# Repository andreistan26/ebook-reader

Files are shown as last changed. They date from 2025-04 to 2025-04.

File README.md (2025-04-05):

# OpenBook - Andrei Stan 331CC

Untitled-2025-03-29-1929(1)

## Descriere Functionalitate Hardware
- Tableta este controlata prin cele 3 butoane
- ESP-ul comunica cu memoria flash si SD card-ul
- Trimite date la display pentru afisarea continutului din flash/sd card
- De la USB se folosesc linia de date si cea de putere pentru alimentare
- Linia de alimentare incarca bateria tabletei
- Se folosesc protocoalele i2c si spi pentru comunicatie
- UART se poate folosi prin testpad-uri pentru debugging
## ESP32 Pini
|Pin|Semnal|Descriere|
|---|---|---|
|EN|RESET|exact ce spune semanalul
|IO0|INT_RTC| conectat la modulul RTC care poate emite intreruperi la anumite alarme/timere
|IO1|32KHz| transmite un semanl de 32Khz care este folosit pentru ceasul tabletei
|IO2|MISO| pentru primirea datelor de la periferic (ex. SD card reader, Flash memorie)
|IO3|EPD_BUSY| pentru a trimite date numai atunci cand display-ul este gata de randat, epaper este incet, deci avem nevoie de acest semnal
|IO4|SS_SD| folosit pentru detectia sd cardului, daca este prezent
|IO5|EPD_DC| comunicatie seriala cu e-paper display-ul
|IO6|SCK| ceas pentru comunicatia SPI cu celelalte componente SPI
|IO7|MOSI| pentru transmisia informatiilor pentru card SD, memorie flash si display
|IO8|GPIO8| neutilizat
|IO9|IO/BOOT| a fost apasat butonul de pornire
|IO10|EPD_CS| Chip select pentru comunicatia seriala
|IO11|FLASH_CS| Chip select pentru memoria flash
|IO12|USB_D-| transfer de date USB diferential -
|IO13|USB_D+| transfer de date USB diferential +
|IO15|IO/Change| butonul de schimbat pagina este apasat
|TXD0| TX| Tx pe UART, este folosit numai la testpad-uri pentru debugging
|RXD0| RX| Rx pe UART, este folosit numai la testpad-uri  pentru debugging
|IO18| RTC_RST| resetare a ceasului de 32Khz
|IO19| I2C_PW| alimentare si chip-select pentru senzor
|IO20| EPD_3v3_c| controleaza transzistorul prin care este alimentat display-ul (nu putem alimenta direct din el sau cel putin e bad practice)
|IO21| SDA| linie de date pentru comunicarea i2c 
|IO22| SCL| semnalul de ceas pentru comunicatrea i2c
|IO23| EPD_RST| resetare a display-ului

## Design Log \ Decizii

* Mufa USB a fost modificata pentru a evita erorile DRC
* Traseele de putere au fost facute prima data, dupa care am folosit autorouter-ul pentru a completa
* Am mutat toate gaurile de pe carcasa si dimensiunile acesteia pentru a intra PCB ul

## BOM
|Qty|Device|Parts|DATASHEET|DESCRIPTION|MOUSER_PRICE-STOCK|
|---|---|-----|---|---|---|
|1|ADAFRUIT_LEDCHIP-LED0603|CHG_LED|https://www.vishay.com/doc?82437||https://ro.mouser.com/ProductDetail/Vishay-Semiconductors/VLMY1301-GS08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|
|1|ESP32_WROVER_EAGLE-LTSPICE_RR0402|R15|https://www.vishay.com/doc?20035||https://ro.mouser.com/ProductDetail/Vishay-Dale/CRCW040240K2FKED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|
|1|ESP32_WROVER_EAGLE-LTSPICE_RR0402|R21|https://www.vishay.com/doc?20035|||
|7|EAGLE-LTSPICE_CC0402|"C3, C4, C5, C9, C18, C19, C_DELAY"|https://ro.mouser.com/datasheet/2/447/KEM_C1006_X5R_SMD-3316465.pdf||https://ro.mouser.com/ProductDetail/KEMET/C0402C475K8PACTU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|
|2|ESP32_WROVER_EAGLE-LTSPICE_CC0402|"C24, C25"|https://ro.mouser.com/datasheet/2/447/KEM_C1006_X5R_SMD-3316465.pdf||https://ro.mouser.com/ProductDetail/KEMET/C0402C475K8PACTU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|
|1|RCL_CPOL-EUCT3528|C28|https://ro.mouser.com/datasheet/2/447/KEM_T2073_T59X-3316825.pdf||https://ro.mouser.com/ProductDetail/KEMET/T598B335M035ATE150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|
|1|ESP32_WROVER_EAGLE-LTSPICE_RR0402|R14|https://www.vishay.com/doc?20035||https://ro.mouser.com/ProductDetail/Vishay-Dale/CRCW040240K2FKED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|
|12|ESP32_WROVER_EAGLE-LTSPICE_RR0402|"R1, R1_PINH1, R2, R2_PINH1, R3, R5, R6, R7, R8, R10, R11, R17"|https://www.vishay.com/doc?20035|||
|3|ESP32_WROVER_EAGLE-LTSPICE_RR0402|"R_BOOT, R_CHANGE, R_RESET"|https://www.vishay.com/doc?20035|||
|1|ESP32_WROVER_EAGLE-LTSPICE_CC0402|C21|https://ro.mouser.com/datasheet/2/447/KEM_C1006_X5R_SMD-3316465.pdf||https://ro.mouser.com/ProductDetail/KEMET/C0402C475K8PACTU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|
|1|112A-TAAR-R03_ATTEND|J1|https://www.attend.com.tw/data/download/file/112A-TAAR-R03_Spec.pdf|"Micro SD Card Socket, Push-Push Type, Top Mount, SMT, H=1.83mm, 10u"|https://www.digikey.com/en/products/detail/attend-technology/112A-TAAR-R03/17633923|
|1|ESP32_WROVER_EAGLE-LTSPICE_RR0402|R_CAPACITOR|https://www.vishay.com/doc?20035|||
|1|EAGLE-LTSPICE_CC0402|C2|https://ro.mouser.com/datasheet/2/447/KEM_C1006_X5R_SMD-3316465.pdf||https://ro.mouser.com/ProductDetail/KEMET/C0402C475K8PACTU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|
|10|EAGLE-LTSPICE_CC0402|"C7, C8, C10, C11, C12, C13, C14, C15, C16, C17"|https://ro.mouser.com/datasheet/2/447/KEM_C1006_X5R_SMD-3316465.pdf||https://ro.mouser.com/ProductDetail/KEMET/C0402C475K8PACTU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|
|1|ESP32_WROVER_EAGLE-LTSPICE_RR0402|R12|https://www.vishay.com/doc?20035|||
|1|ESP32_WROVER_EAGLE-LTSPICE_RR0402|R1_BAT|https://www.vishay.com/doc?20035|||
|1|ESP32_WROVER_SPARKFUN-DISCRETESEMI_MOSFET_PCH-DMG2305UX-7|Q1|https://www.diodes.com/assets/Datasheets/DMG2305UX.pdf||https://www.digikey.ro/en/products/detail/diodes-incorporated/DMG2305UX-7/4340667|
|1|ESP32_WROVER_SPARKFUN-DISCRETESEMI_MOSFET_PCH-DMG2305UX-7|Q3|https://www.diodes.com/assets/Datasheets/DMG2305UX.pdf||https://www.digikey.ro/en/products/detail/diodes-incorporated/DMG2305UX-7/4340667|
|1|ESP32_WROVER_EAGLE-LTSPICE_RR0402|R16|https://www.vishay.com/doc?20035|||
|2|EAGLE-LTSPICE_CC0402|"C22, C23"|https://ro.mouser.com/datasheet/2/447/KEM_C1006_X5R_SMD-3316465.pdf||https://ro.mouser.com/ProductDetail/KEMET/C0402C475K8PACTU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|
|2|ESP32_WROVER_EAGLE-LTSPICE_CC0402|"C26, C27"|https://ro.mouser.com/datasheet/2/447/KEM_C1006_X5R_SMD-3316465.pdf||https://ro.mouser.com/ProductDetail/KEMET/C0402C475K8PACTU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|
|1|ESP32_WROVER_EAGLE-LTSPICE_CC0402|C20|https://ro.mouser.com/datasheet/2/447/KEM_C1006_X5R_SMD-3316465.pdf||https://ro.mouser.com/ProductDetail/KEMET/C0402C475K8PACTU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|
|2|ESP32_WROVER_EAGLE-LTSPICE_RR0402|"R19, R20"|https://www.vishay.com/doc?20035|||
|1|744043680IND_4828-WE-TPC_WRE|L3|https://www.we-online.com/components/products/datasheet/744043680.pdf||https://ro.mouser.com/ProductDetail/Wurth-Elektronik/744043680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|
|1|BD5229G-TR|IC1|https://fscdn.rohm.com/en/products/databook/datasheet/ic/power/voltage_detector/bd52xxg-e.pdf|"Voltage Detector with Adjustable Delay Time: CMOS processes are utilized to develop high precision  low current consumption CMOS reset ICs that allow arbitrary setting of the delay time. The extensive lineup includes both Nch Open Drain and CMOS output types in a wide range of detection voltages (from 2.3V to 6.0V, in 0.1V steps) enabling selection of the ideal solution based on customer requirements. In addition the entire series is of course both lead-free and RoHS-compliant."|https://www.mouser.co.uk/ProductDetail/ROHM-Semiconductor/BD5229G-TR?qs=4kLU8WoGk0vvnhrrYwdszw%3D%3D|
|1|ESP32_WROVER_BME680_BME680|SENSOR2|https://ro.mouser.com/datasheet/2/783/BST_BME680_DS001-1509608.pdf| Integrated Environmental Unit |https://ro.mouser.com/ProductDetail/Bosch-Sensortec/BME680?qs=v271MhAjFHjo0yA%2FC4OnDQ%3D%3D|
|3|BUTTON_CUSYOMV1|"BOOT_BUTTON, CHANGE_BUTTON, RESET_BUTTON"|https://4donline.ihs.com/images/VipMasterIC/IC/PANA/PANAS45028/PANAS45028-1.pdf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||https://ro.mouser.com/ProductDetail/Panasonic/EVQ-9P701P?qs=NPkb10g2yLBKCwpELvsGNg%3D%3D|
|1|CPH3225A|C6|https://mm.digikey.com/Volume0/opasdata/d220001/medias/docus/6537/rev05-CPHCPM.pdf| 11 mF (EDLC) Supercapacitor 3.3 V 1210 (3225 Metric) - - ||
|1|DS3231SN#|U4|https://ro.mouser.com/datasheet/2/609/DS3231-3421123.pdf| Extremely Accurate I C-Integrated RTC/TCXO/Crystal ||
|1|ESP32-C6-WROOM-1-N8|U1|https://www.espressif.com/sites/default/files/documentation/esp32-c6-wroom-1_wroom-1u_datasheet_en.pdf|" Multiprotocol Modules ESP32-C6 module, Wi-Fi 6 in 2.4 GHz band, Bluetooth 5, Zigbee 3.0 and Thread. ESP34-WROOM Compatible - ENGINEERING SAMPLE "||
|1|ESP32C6_VARISTORCN1812|R18|https://mm.digikey.com/Volume0/opasdata/d220001/medias/docus/2123/CTVS_Standard_Rev2015.pdf||https://www.digikey.be/en/products/detail/epcos-tdk-electronics/CN1812K11G/635074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|
|2|ESP32_WROVER_AVX---SD0805S020S1R0_AVX_SD0805S020S1R0_0_0AVX_SD0805S020S1R0_0_0|"D1, D13"|http://datasheets.avx.com/schottky.pdf|||
|1|ESP32_WROVER_SPARKFUN-IC-POWER_MCP73831|MCP73831|https://ro.mouser.com/datasheet/2/268/MCP73831_Family_Data_Sheet_DS20001984H-3441711.pdf||https://www.mouser.dk/ProductDetail/Microchip-Technology/MCP73831T-3ACI-OT?qs=yUQqVecv4quInAWkk8YFWg%3D%3D|
|1|FH34SRJ-24S-0.5SH_99_|J3|https://ro.mouser.com/datasheet/2/185/FH34SRJ_24S_0_5SH_99__CL0580_1255_6_99_2DDrawing_0-1615044.pdf|"24 Position FFC, FPC Connector Contacts, Top and Bottom 0.020"" (0.50mm) Surface Mount, Right Angle"|https://www.mouser.co.uk/ProductDetail/Hirose-Connector/FH34SRJ-24S-0.5SH99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|
|1|MAX17048G+T10|U2|https://ro.mouser.com/datasheet/2/609/MAX17048_MAX17049-3469099.pdf| 3 A 1-Cell/2-Cell Fuel Gauge with ModelGauge ||
|3|MBR0530|"D3, D5, D7"|https://www.onsemi.cn/pdf/datasheet/mbr0530-d.pdf| Diode Schottky 30 V 500mA Surface Mount SOD-123 ||
|6|PGB1010603MR|"D2, D4, D6, D8, D10, D11"|https://www.littelfuse.com/assetdocs/pulseguard-esd-suppressors-pgb1-datasheet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| 150V (Typ) Clamp - Ipp Tvs Diode Surface Mount 0603 (1608 Metric) ||
|1|QWIIC_CONNECTORJS-1MM|J2|https://ro.mouser.com/datasheet/2/813/Qwiic_Connector_Datasheet-1223982.pdf||https://ro.mouser.com/ProductDetail/SparkFun/PRT-14417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|
|1|SAMACSYS_PARTS_USB4110-GF-A|J4|https://ro.mouser.com/datasheet/2/837/GCT_USB4110_Product_Drawing___20k_cycles-3455479.pdf|CONN USB 2.0 TYPE-C R/A SMT|https://www.mouser.co.uk/ProductDetail/GCT/USB4110-GF-A?qs=KUoIvG%2F9IlYiZvIXQjyJeA%3D%3D|
|1|SI1308EDL-T1-GE3|Q2|https://www.vishay.com/docs/63399/si1308edl.pdf|" Si1308EDL-T1-GE3 N-channel MOSFET Transistor, 1.5 A, 30 V, 3-Pin SC-70 Siliconix / Vishay SI1308EDL-T1-GE3 "||
|1|USBLC6-2SC6Y|D9|https://ro.mouser.com/datasheet/2/389/usblc6_2sc6y-1852505.pdf| 17V Clamp 5A (8/20 s) Ipp Tvs Diode Surface Mount SOT-23-6 |https://ro.mouser.com/ProductDetail/STMicroelectronics/USBLC6-2SC6Y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|
|1|W25Q512JVEIQ|U3|https://www.winbond.com/resource-files/W25Q512JV%20SPI%20RevB%2006252019%20KMS.pdf| FLASH - NOR Memory IC 512Mb (64M x 8) SPI - Quad I/O 133 MHz 8-WSON (8x6) ||
|1|XC6220A331MR-G|IC2|https://ro.mouser.com/datasheet/2/760/xc6220-3371556.pdf|LDO Voltage Regulators|https://www.mouser.co.uk/ProductDetail/Torex-Semiconductor/XC6220A331MR-G?qs=AsjdqWjXhJ8ZSWznL1J0gg%3D%3D|

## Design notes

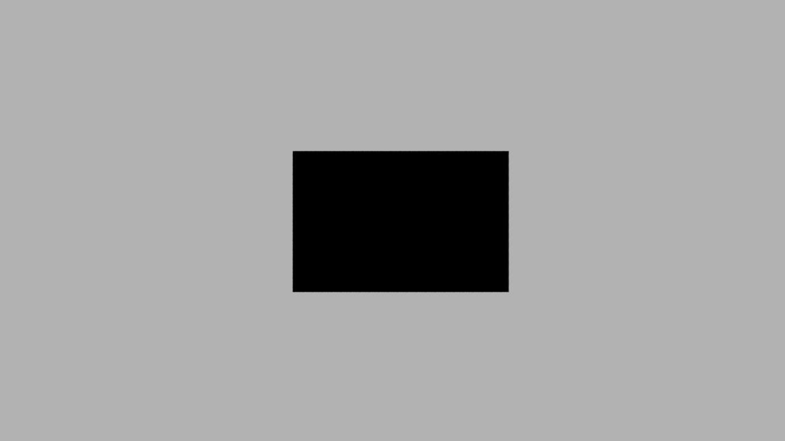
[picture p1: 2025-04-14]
Images/screen.png

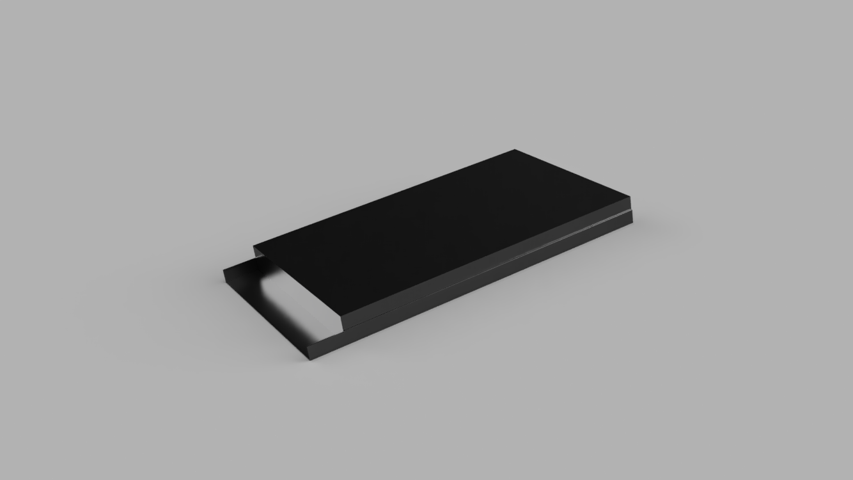
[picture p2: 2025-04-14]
Images/battery.png

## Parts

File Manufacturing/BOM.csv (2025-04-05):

Qty | Value | Device | Package | Parts | Description | ARROW_PART_NUMBER | ARROW_PRICE-STOCK | AVAILABILITY | CENTROID_NOT_SPECIFIED | CHECK_PRICES | COPYRIGHT | DATASHEET | DESCRIPTION | DIGIKEY_DESCRIPTION | DIGIKEY_PART_NUMBER | HEIGHT | LEAD_FREE | MANUFACTURER_NAME | MANUFACTURER_PART_NUMBER | MF | MFR_NAME | MOUSER_PART_NUMBER | MOUSER_PRICE-STOCK | MOUSER_TESTING_PART_NUMBER | MOUSER_TESTING_PRICE-STOCK | MP | MPN | PACKAGE | POPULARITY | PREFIX | PRICE | PROD_ID | PURCHASE-URL | ROHS | SNAPEDA_LINK | SPICEMODEL | SPICEPREFIX | TEMPERATURE_RANGE_HIGH | TEMPERATURE_RANGE_LOW | TP_SIGNAL_NAME | VALUE
1 |  | ADAFRUIT_LEDCHIP-LED0603 | ADAFRUIT_CHIP-LED0603 | CHG_LED | LED |  |  |  |  |  |  | https://www.vishay.com/doc?82437 |  |  |  |  |  |  |  |  |  |  | https://ro.mouser.com/ProductDetail/Vishay-Semiconductors/VLMY1301-GS08
1 |  | SJ | SJ | SJ1 | SMD solder JUMPER |  |  |  |  |  |  |  |  |  |  |  |  |  |  |  |  |  |  |  |  |  |  |  | 3
1 | 0.47 | ESP32_WROVER_EAGLE-LTSPICE_RR0402 | ESP32_WROVER_EAGLE-LTSPICE_R0402 | R15 | RESISTOR, European symbol |  |  |  |  |  |  | https://www.vishay.com/doc?20035 |  |  |  |  |  |  |  |  |  |  | https://ro.mouser.com/ProductDetail/Vishay-Dale/CRCW040240K2FKED?qs=rzhQWu8UUS3g49JmcwYN7w%3D%3D&gad_source=1 |  |  |  |  |  |  |  |  |  |  |  |  | NONE | R
1 | 100K | ESP32_WROVER_EAGLE-LTSPICE_RR0402 | ESP32_WROVER_EAGLE-LTSPICE_R0402 | R21 | RESISTOR, European symbol |  |  |  |  |  |  | https://www.vishay.com/doc?20035 |  |  |  |  |  |  |  |  |  | https://eu.mouser.com/ProductDetail/Vishay-Dale/CRCW040240K2FKED?qs=rzhQWu8UUS3g49JmcwYN7w%3D%3D&gad_source=1 |  |  |  |  |  |  |  |  |  |  |  |  |  | NONE | R
7 | 100nF | EAGLE-LTSPICE_CC0402 | EAGLE-LTSPICE_C0402 | C3, C4, C5, C9, C18, C19, C_DELAY | CAPACITOR, European symbol |  |  |  |  |  |  | https://ro.mouser.com/datasheet/2/447/KEM_C1006_X5R_SMD-3316465.pdf |  |  |  |  |  |  |  |  |  |  | https://ro.mouser.com/ProductDetail/KEMET/C0402C475K8PACTU |  |  |  |  |  |  |  |  |  |  |  |  | NONE | C
2 | 100nF | ESP32_WROVER_EAGLE-LTSPICE_CC0402 | ESP32_WROVER_EAGLE-LTSPICE_C0402 | C24, C25 | CAPACITOR, European symbol |  |  |  |  |  |  | https://ro.mouser.com/datasheet/2/447/KEM_C1006_X5R_SMD-3316465.pdf |  |  |  |  |  |  |  |  |  |  | https://ro.mouser.com/ProductDetail/KEMET/C0402C475K8PACTU |  |  |  |  |  |  |  |  |  |  |  |  | NONE | C
1 | 100uF | RCL_CPOL-EUCT3528 | RCL_CT3528 | C28 | POLARIZED CAPACITOR, European symbol |  |  |  |  |  |  | https://ro.mouser.com/datasheet/2/447/KEM_T2073_T59X-3316825.pdf |  |  |  |  |  |  |  |  |  |  | https://ro.mouser.com/ProductDetail/KEMET/T598B335M035ATE150 |  |  |  |  |  | 0 |  |  |  |  |  |  |  | C
1 | 10K | ESP32_WROVER_EAGLE-LTSPICE_RR0402 | ESP32_WROVER_EAGLE-LTSPICE_R0402 | R14 | RESISTOR, European symbol |  |  |  |  |  |  | https://www.vishay.com/doc?20035 |  |  |  |  |  |  |  |  |  |  | https://ro.mouser.com/ProductDetail/Vishay-Dale/CRCW040240K2FKED?qs=rzhQWu8UUS3g49JmcwYN7w%3D%3D&gad_source=1 |  |  |  |  |  |  |  |  |  |  |  |  | NONE | R
12 | 10K | ESP32_WROVER_EAGLE-LTSPICE_RR0402 | ESP32_WROVER_EAGLE-LTSPICE_R0402 | R1, R1_PINH1, R2, R2_PINH1, R3, R5, R6, R7, R8, R10, R11, R17 | RESISTOR, European symbol |  |  |  |  |  |  | https://www.vishay.com/doc?20035 |  |  |  |  |  |  |  |  |  | https://eu.mouser.com/ProductDetail/Vishay-Dale/CRCW040240K2FKED?qs=rzhQWu8UUS3g49JmcwYN7w%3D%3D&gad_source=1 |  |  |  |  |  |  |  |  |  |  |  |  |  | NONE | R
3 | 10k | ESP32_WROVER_EAGLE-LTSPICE_RR0402 | ESP32_WROVER_EAGLE-LTSPICE_R0402 | R_BOOT, R_CHANGE, R_RESET | RESISTOR, European symbol |  |  |  |  |  |  | https://www.vishay.com/doc?20035 |  |  |  |  |  |  |  |  |  | https://eu.mouser.com/ProductDetail/Vishay-Dale/CRCW040240K2FKED?qs=rzhQWu8UUS3g49JmcwYN7w%3D%3D&gad_source=1 |  |  |  |  |  |  |  |  |  |  |  |  |  | NONE | R
1 | 10uF | ESP32_WROVER_EAGLE-LTSPICE_CC0402 | ESP32_WROVER_EAGLE-LTSPICE_C0402 | C21 | CAPACITOR, European symbol |  |  |  |  |  |  | https://ro.mouser.com/datasheet/2/447/KEM_C1006_X5R_SMD-3316465.pdf |  |  |  |  |  |  |  |  |  |  | https://ro.mouser.com/ProductDetail/KEMET/C0402C475K8PACTU |  |  |  |  |  |  |  |  |  |  |  |  | NONE | C
1 | 112A-TAAR-R03_ATTEND | 112A-TAAR-R03_ATTEND | 112ATAARR03ATTEND | J1 | Micro SD Card Socket, Push-Push Type, Top Mount, SMT, H=1.83mm, 10u |  |  |  |  |  |  | https://www.attend.com.tw/data/download/file/112A-TAAR-R03_Spec.pdf | Micro SD Card Socket | Push-Push Type | Top Mount | SMT | H=1.83mm | 10u |  |  | 1.9mm |  | ATTEND | 112A-TAAR-R03 ATTEND |  |  |  | https://www.digikey.com/en/products/detail/attend-technology/112A-TAAR-R03/17633923
1 | 15 | ESP32_WROVER_EAGLE-LTSPICE_RR0402 | ESP32_WROVER_EAGLE-LTSPICE_R0402 | R_CAPACITOR | RESISTOR, European symbol |  |  |  |  |  |  | https://www.vishay.com/doc?20035 |  |  |  |  |  |  |  |  |  | https://eu.mouser.com/ProductDetail/Vishay-Dale/CRCW040240K2FKED?qs=rzhQWu8UUS3g49JmcwYN7w%3D%3D&gad_source=1 |  |  |  |  |  |  |  |  |  |  |  |  |  | NONE | R
1 | 1uF | EAGLE-LTSPICE_CC0402 | EAGLE-LTSPICE_C0402 | C2 | CAPACITOR, European symbol |  |  |  |  |  |  | https://ro.mouser.com/datasheet/2/447/KEM_C1006_X5R_SMD-3316465.pdf |  |  |  |  |  |  |  |  |  |  | https://ro.mouser.com/ProductDetail/KEMET/C0402C475K8PACTU |  |  |  |  |  |  |  |  |  |  |  |  | NONE | C
10 | 1uF/50V | EAGLE-LTSPICE_CC0402 | EAGLE-LTSPICE_C0402 | C7, C8, C10, C11, C12, C13, C14, C15, C16, C17 | CAPACITOR, European symbol |  |  |  |  |  |  | https://ro.mouser.com/datasheet/2/447/KEM_C1006_X5R_SMD-3316465.pdf |  |  |  |  |  |  |  |  |  |  | https://ro.mouser.com/ProductDetail/KEMET/C0402C475K8PACTU |  |  |  |  |  |  |  |  |  |  |  |  | NONE | C
1 | 2.2 | ESP32_WROVER_EAGLE-LTSPICE_RR0402 | ESP32_WROVER_EAGLE-LTSPICE_R0402 | R12 | RESISTOR, European symbol |  |  |  |  |  |  | https://www.vishay.com/doc?20035 |  |  |  |  |  |  |  |  |  | https://eu.mouser.com/ProductDetail/Vishay-Dale/CRCW040240K2FKED?qs=rzhQWu8UUS3g49JmcwYN7w%3D%3D&gad_source=1 |  |  |  |  |  |  |  |  |  |  |  |  |  | NONE | R
1 | 200 | ESP32_WROVER_EAGLE-LTSPICE_RR0402 | ESP32_WROVER_EAGLE-LTSPICE_R0402 | R1_BAT | RESISTOR, European symbol |  |  |  |  |  |  | https://www.vishay.com/doc?20035 |  |  |  |  |  |  |  |  |  | https://eu.mouser.com/ProductDetail/Vishay-Dale/CRCW040240K2FKED?qs=rzhQWu8UUS3g49JmcwYN7w%3D%3D&gad_source=1 |  |  |  |  |  |  |  |  |  |  |  |  |  | NONE | R
2 | 20V/4.2A/52mO/1.4W | ESP32_WROVER_SPARKFUN-DISCRETESEMI_MOSFET_PCH-DMG2305UX-7 | ESP32_WROVER_SPARKFUN-DISCRETESEMI_SOT23-3 | Q1, Q3 | P-channel MOSFETs |  |  |  |  |  |  | https://www.diodes.com/assets/Datasheets/DMG2305UX.pdf |  |  |  |  |  |  |  |  |  |  | https://www.digikey.ro/en/products/detail/diodes-incorporated/DMG2305UX-7/4340667 |  |  |  |  |  |  |  |  | TRAN-14388 |  |  |  |  |  |  |  |  | 20V/4.2A/52mO/1.4W
1 | 2K | ESP32_WROVER_EAGLE-LTSPICE_RR0402 | ESP32_WROVER_EAGLE-LTSPICE_R0402 | R16 | RESISTOR, European symbol |  |  |  |  |  |  | https://www.vishay.com/doc?20035 |  |  |  |  |  |  |  |  |  | https://eu.mouser.com/ProductDetail/Vishay-Dale/CRCW040240K2FKED?qs=rzhQWu8UUS3g49JmcwYN7w%3D%3D&gad_source=1 |  |  |  |  |  |  |  |  |  |  |  |  |  | NONE | R
2 | 4.7uF | EAGLE-LTSPICE_CC0402 | EAGLE-LTSPICE_C0402 | C22, C23 | CAPACITOR, European symbol |  |  |  |  |  |  | https://ro.mouser.com/datasheet/2/447/KEM_C1006_X5R_SMD-3316465.pdf |  |  |  |  |  |  |  |  |  |  | https://ro.mouser.com/ProductDetail/KEMET/C0402C475K8PACTU |  |  |  |  |  |  |  |  |  |  |  |  | NONE | C
2 | 4.7uF | ESP32_WROVER_EAGLE-LTSPICE_CC0402 | ESP32_WROVER_EAGLE-LTSPICE_C0402 | C26, C27 | CAPACITOR, European symbol |  |  |  |  |  |  | https://ro.mouser.com/datasheet/2/447/KEM_C1006_X5R_SMD-3316465.pdf |  |  |  |  |  |  |  |  |  |  | https://ro.mouser.com/ProductDetail/KEMET/C0402C475K8PACTU |  |  |  |  |  |  |  |  |  |  |  |  | NONE | C
1 | 4.7uF/25V | ESP32_WROVER_EAGLE-LTSPICE_CC0402 | ESP32_WROVER_EAGLE-LTSPICE_C0402 | C20 | CAPACITOR, European symbol |  |  |  |  |  |  | https://ro.mouser.com/datasheet/2/447/KEM_C1006_X5R_SMD-3316465.pdf |  |  |  |  |  |  |  |  |  |  | https://ro.mouser.com/ProductDetail/KEMET/C0402C475K8PACTU |  |  |  |  |  |  |  |  |  |  |  |  | NONE | C
2 | 5K1 | ESP32_WROVER_EAGLE-LTSPICE_RR0402 | ESP32_WROVER_EAGLE-LTSPICE_R0402 | R19, R20 | RESISTOR, European symbol |  |  |  |  |  |  | https://www.vishay.com/doc?20035 |  |  |  |  |  |  |  |  |  | https://eu.mouser.com/ProductDetail/Vishay-Dale/CRCW040240K2FKED?qs=rzhQWu8UUS3g49JmcwYN7w%3D%3D&gad_source=1 |  |  |  |  |  |  |  |  |  |  |  |  |  | NONE | R
1 | 68uH | 744043680IND_4828-WE-TPC_WRE | IND_4828-WE-TPC_WRE | L3 |  |  |  |  |  |  | Copyright (C) 2024 Ultra Librarian. All rights reserved. | https://www.we-online.com/components/products/datasheet/744043680.pdf |  |  |  |  |  |  | 744043680 |  | Wurth Electronics |  | https://ro.mouser.com/ProductDetail/Wurth-Elektronik/744043680?qs=PGXP4M47uW6VkZq%252BkzjrHA%3D%3D
1 | BD5229G-TR | BD5229G-TR | SOT95P280X125-5N | IC1 | Voltage Detector with Adjustable Delay Time: CMOS processes are utilized to develop high precision, low current consumption CMOS reset ICs that allow arbitrary setting of the delay time. The extensive lineup includes both Nch Open Drain and CMOS output types in a wide range of detection voltages (from 2.3V to 6.0V, in 0.1V steps), enabling selection of the ideal solution based on customer requirements. In addition, the entire series is of course both lead-free and RoHS-compliant. |  |  |  |  |  |  | https://fscdn.rohm.com/en/products/databook/datasheet/ic/power/voltage_detector/bd52xxg-e.pdf | Voltage Detector with Adjustable Delay Time: CMOS processes are utilized to develop high precision | low current consumption CMOS reset ICs that allow arbitrary setting of the delay time. The extensive lineup includes both Nch Open Drain and CMOS output types in a wide range of detection voltages (from 2.3V to 6.0V | in 0.1V steps) | enabling selection of the ideal solution based on customer requirements. In addition | the entire series is of course both lead-free and RoHS-compliant. |  |  | 1.25mm |  | ROHM Semiconductor | BD5229G-TR |  |  | 755-BD5229G-TR | https://www.mouser.co.uk/ProductDetail/ROHM-Semiconductor/BD5229G-TR?qs=4kLU8WoGk0vvnhrrYwdszw%3D%3D
1 | BME688 | ESP32_WROVER_BME680_BME680 | ESP32_WROVER_BME680_PSON80P300X300X100-8N | SENSOR2 | Integrated Environmental Unit |  |  | Unavailable |  |  |  | https://ro.mouser.com/datasheet/2/783/BST_BME680_DS001-1509608.pdf | Integrated Environmental Unit |  |  |  |  |  |  | Bosch Sensortec |  |  | https://ro.mouser.com/ProductDetail/Bosch-Sensortec/BME680?qs=v271MhAjFHjo0yA%2FC4OnDQ%3D%3D |  |  | BME680 |  | LGA-8 Bosch Tools |  |  | None
3 | BUTTON_CUSYOMV1 | BUTTON_CUSYOMV1 | MYBUTTON | BOOT_BUTTON, CHANGE_BUTTON, RESET_BUTTON |  |  |  |  |  |  |  | https://4donline.ihs.com/images/VipMasterIC/IC/PANA/PANAS45028/PANAS45028-1.pdf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 |  |  |  |  |  |  |  |  |  |  | https://ro.mouser.com/ProductDetail/Panasonic/EVQ-9P701P?qs=NPkb10g2yLBKCwpELvsGNg%3D%3D
1 | CPH3225A | CPH3225A | CAPCP3225X100N | C6 | Cap 0.011F 3.3V 1210 Flat Check availability |  |  | Not in stock |  | https://www.snapeda.com/parts/CPH3225A/Seiko+Instruments/view-part/?ref=eda |  | https://mm.digikey.com/Volume0/opasdata/d220001/medias/docus/6537/rev05-CPHCPM.pdf | 11 mF (EDLC) Supercapacitor 3.3 V 1210 (3225 Metric) - - |  |  |  |  |  |  | Seiko Instruments |  |  |  |  |  | CPH3225A |  | 1210 Seiko |  |  | None |  | https://www.snapeda.com/api/url_track_click_mouser/?unipart_id=562593&manufacturer=Seiko Instruments&part_name=CPH3225A&search_term=None |  | https://www.snapeda.com/parts/CPH3225A/Seiko+Instruments/view-part/?ref=snap
1 | DS3231SN# | DS3231SN# | SOIC127P1032X265-16N | U4 | Real Time Clock Serial 16-Pin SOIC W T/R Check availability |  |  | In Stock |  | https://www.snapeda.com/parts/DS3231SN%23/Analog+Devices/view-part/?ref=eda |  | https://ro.mouser.com/datasheet/2/609/DS3231-3421123.pdf | Extremely Accurate I²C-Integrated RTC/TCXO/Crystal |  |  |  |  |  |  | Analog Devices |  |  |  |  |  | DS3231SN# |  | SOIC-16 Maxim |  |  | None |  | https://www.snapeda.com/api/url_track_click_mouser/?unipart_id=99048&manufacturer=Analog Devices&part_name=DS3231SN#&search_term=None |  | https://www.snapeda.com/parts/DS3231SN%23/Analog+Devices/view-part/?ref=snap
1 | ESP32-C6-WROOM-1-N8 | ESP32-C6-WROOM-1-N8 | XCVR_ESP32-C6-WROOM-1-N8 | U1 | Check availability |  |  | In Stock |  | https://www.snapeda.com/parts/ESP32-C6-WROOM-1-N8/Espressif+Systems/view-part/?ref=eda |  | https://www.espressif.com/sites/default/files/documentation/esp32-c6-wroom-1_wroom-1u_datasheet_en.pdf | Multiprotocol Modules ESP32-C6 module | Wi-Fi 6 in 2.4 GHz band | Bluetooth 5 | Zigbee 3.0 and Thread. ESP34-WROOM Compatible - ENGINEERING SAMPLE |  |  |  |  |  |  | Espressif Systems |  |  |  |  |  | ESP32-C6-WROOM-1-N8 |  | None |  |  | None |  |  |  | https://www.snapeda.com/parts/ESP32-C6-WROOM-1-N8/Espressif+Systems/view-part/?ref=snap
1 | ESP32C6_VARISTORCN1812 | ESP32C6_VARISTORCN1812 | ESP32C6_VARISTOR_CT/CN1812 | R18 | VARISTOR |  |  |  |  |  |  | https://mm.digikey.com/Volume0/opasdata/d220001/medias/docus/2123/CTVS_Standard_Rev2015.pdf |  |  |  |  |  |  |  |  |  |  | https://www.digikey.be/en/products/detail/epcos-tdk-electronics/CN1812K11G/635074 |  |  |  |  |  | 0
2 | ESP32_WROVER_AVX---SD0805S020S1R0_AVX_SD0805S020S1R0_0_0AVX_SD0805S020S1R0_0_0 | ESP32_WROVER_AVX---SD0805S020S1R0_AVX_SD0805S020S1R0_0_0AVX_SD0805S020S1R0_0_0 | ESP32_WROVER_AVX---SD0805S020S1R0_AVX_SD0805S020S1R0_0 | D1, D13 | Schottky Barrier Rectifier Diode |  |  |  | No |  |  | http://datasheets.avx.com/schottky.pdf |  | DIODE SCHOTTKY 20V 1A 0805 | 478-7800-1-ND |  | yes |  |  | AVX |  | 581-SD0805S020S1R0 |  |  |  |  |  | 0805 (2012 metric) |  | D |  |  |  | yes |  |  |  | +125°C | -55°C
1 | ESP32_WROVER_SPARKFUN-IC-POWER_MCP73831 | ESP32_WROVER_SPARKFUN-IC-POWER_MCP73831 | ESP32_WROVER_SPARKFUN-IC-POWER_SOT23-5 | MCP73831 | MCP73831T Li-Ion, Li-Pol Controller |  |  |  |  |  |  | https://ro.mouser.com/datasheet/2/268/MCP73831_Family_Data_Sheet_DS20001984H-3441711.pdf |  |  |  |  |  |  |  |  |  |  | https://www.mouser.dk/ProductDetail/Microchip-Technology/MCP73831T-3ACI-OT?qs=yUQqVecv4quInAWkk8YFWg%3D%3D |  |  |  |  |  |  |  |  | IC-09995
1 | FH34SRJ-24S-0.5SH_99_ | FH34SRJ-24S-0.5SH_99_ | FH34SRJ24S05SH99 | J3 | (0.50mm) Surface Mount, Right Angle |  |  |  |  |  |  | https://ro.mouser.com/datasheet/2/185/FH34SRJ_24S_0_5SH_99__CL0580_1255_6_99_2DDrawing_0-1615044.pdf | 24 Position FFC | FPC Connector Contacts | (0.50mm) Surface Mount | Right Angle |  |  | 1.1mm |  | Hirose | FH34SRJ-24S-0.5SH(99) |  |  | 798-FH34SRJ24S05SH99 | https://www.mouser.co.uk/ProductDetail/Hirose-Connector/FH34SRJ-24S-0.5SH99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
1 | MAX17048G+T10 | MAX17048G+T10 | SON50P200X200X80-9N | U2 | Check availability |  |  | In Stock |  | https://www.snapeda.com/parts/MAX17048G+T10/Analog+Devices/view-part/?ref=eda |  | https://ro.mouser.com/datasheet/2/609/MAX17048_MAX17049-3469099.pdf | 3µA 1-Cell/2-Cell Fuel Gauge with ModelGauge |  |  |  |  |  |  | Analog Devices |  |  |  |  |  | MAX17048G+T10 |  | TDFN-8 Maxim |  |  | None |  | https://www.snapeda.com/api/url_track_click_mouser/?unipart_id=329239&manufacturer=Analog Devices&part_name=MAX17048G+T10&search_term=None |  | https://www.snapeda.com/parts/MAX17048G+T10/Analog+Devices/view-part/?ref=snap
3 | MBR0530 | MBR0530 | SOD3716X135N | D3, D5, D7 | ON SEMICONDUCTOR - MBR0530 - DIODE, SCHOTTKY, 0.5A, 30V, SOD-123 |  |  | In Stock |  | https://www.snapeda.com/parts/MBR0530/Onsemi/view-part/?ref=eda |  | https://www.onsemi.cn/pdf/datasheet/mbr0530-d.pdf | Diode Schottky 30 V 500mA Surface Mount SOD-123 |  |  |  |  |  |  | ON Semiconductor |  |  |  |  |  | MBR0530 |  | SOD-123-2 ON Semiconductor |  |  | None |  | https://www.snapeda.com/api/url_track_click_mouser/?unipart_id=179458&manufacturer=ON Semiconductor&part_name=MBR0530&search_term=None |  | https://www.snapeda.com/parts/MBR0530/Onsemi/view-part/?ref=snap
6 | PGB1010603MR | PGB1010603MR | DIOC1608X36N | D2, D4, D6, D8, D10, D11 | Check availability |  |  | In Stock |  | https://www.snapeda.com/parts/PGB1010603MR/Littelfuse/view-part/?ref=eda |  | https://www.littelfuse.com/assetdocs/pulseguard-esd-suppressors-pgb1-datasheet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 | 150V (Typ) Clamp - Ipp Tvs Diode Surface Mount 0603 (1608 Metric) |  |  |  |  |  |  | Littelfuse Inc. |  |  |  |  |  | PGB1010603MR |  | 0603 Littelfuse Inc. |  |  | None |  | https://www.snapeda.com/api/url_track_click_mouser/?unipart_id=5659453&manufacturer=Littelfuse Inc.&part_name=PGB1010603MR&search_term=None |  | https://www.snapeda.com/parts/PGB1010603MR/Littelfuse/view-part/?ref=snap
1 | QWIIC_RIGHT_ANGLE | QWIIC_CONNECTORJS-1MM | JST04_1MM_RA | J2 | SparkFun I2C Standard Qwiic Connector |  |  |  |  |  |  | https://ro.mouser.com/datasheet/2/813/Qwiic_Connector_Datasheet-1223982.pdf |  |  |  |  |  |  |  |  |  |  | https://ro.mouser.com/ProductDetail/SparkFun/PRT-14417?qs=wd5RIQLrsJhgdz%2FpmZ%2F3GQ%3D%3D |  |  |  |  |  |  |  |  | CONN-13694 |  |  |  |  |  |  |  |  | QWIIC_RIGHT_ANGLE
1 | SAMACSYS_PARTS_USB4110-GF-A | SAMACSYS_PARTS_USB4110-GF-A | SAMACSYS_PARTS_USB4110GFA | J4 | CONN USB 2.0 TYPE-C R/A SMT |  |  |  |  |  |  | https://ro.mouser.com/datasheet/2/837/GCT_USB4110_Product_Drawing___20k_cycles-3455479.pdf | CONN USB 2.0 TYPE-C R/A SMT |  |  | 3.26mm |  | GCT (GLOBAL CONNECTOR TECHNOLOGY) | USB4110-GF-A |  |  | 640-USB4110-GF-A | https://www.mouser.co.uk/ProductDetail/GCT/USB4110-GF-A?qs=KUoIvG%2F9IlYiZvIXQjyJeA%3D%3D
1 | SI1308EDL-T1-GE3 | SI1308EDL-T1-GE3 | SOT65P210X110-3N | Q2 | MOSFET N-Ch 30V 1.5A TrenchFET SC70 Vishay Si1308EDL-T1-GE3 N-channel MOSFET Transistor, 1.5 A, 30 V, 3-Pin SC-70 |  |  | In Stock |  | https://www.snapeda.com/parts/SI1308EDL-T1-GE3/Vishay+Siliconix/view-part/?ref=eda |  | https://www.vishay.com/docs/63399/si1308edl.pdf | Si1308EDL-T1-GE3 N-channel MOSFET Transistor | 1.5 A | 30 V | 3-Pin SC-70 | Siliconix / Vishay SI1308EDL-T1-GE3 |  |  |  |  |  |  | Vishay Siliconix |  |  |  |  |  | SI1308EDL-T1-GE3 |  | SOT-323 Vishay Semiconductor |  |  | None |  | https://www.snapeda.com/api/url_track_click_mouser/?unipart_id=274603&manufacturer=Vishay Siliconix&part_name=SI1308EDL-T1-GE3&search_term=None |  | https://www.snapeda.com/parts/SI1308EDL-T1-GE3/Vishay+Siliconix/view-part/?ref=snap
1 | TPTP20R | TPTP20R | TP20R | TP6 | Test pad |  |  |  |  |  |  |  |  |  |  |  |  |  |  |  |  |  |  |  |  |  |  |  | 2 |  |  |  |  |  |  |  |  |  |  | 3V3
1 | TPTP20R | TPTP20R | TP20R | TP7 | Test pad |  |  |  |  |  |  |  |  |  |  |  |  |  |  |  |  |  |  |  |  |  |  |  | 2 |  |  |  |  |  |  |  |  |  |  | EPD_3V3
1 | TPTP20R | TPTP20R | TP20R | TP15 | Test pad |  |  |  |  |  |  |  |  |  |  |  |  |  |  |  |  |  |  |  |  |  |  |  | 2 |  |  |  |  |  |  |  |  |  |  | EPD_3V3_C
1 | TPTP20R | TPTP20R | TP20R | TP11 | Test pad |  |  |  |  |  |  |  |  |  |  |  |  |  |  |  |  |  |  |  |  |  |  |  | 2 |  |  |  |  |  |  |  |  |  |  | EPD_BUSY
1 | TPTP20R | TPTP20R | TP20R | TP12 | Test pad |  |  |  |  |  |  |  |  |  |  |  |  |  |  |  |  |  |  |  |  |  |  |  | 2 |  |  |  |  |  |  |  |  |  |  | EPD_CS
1 | TPTP20R | TPTP20R | TP20R | TP13 | Test pad |  |  |  |  |  |  |  |  |  |  |  |  |  |  |  |  |  |  |  |  |  |  |  | 2 |  |  |  |  |  |  |  |  |  |  | EPD_DC
1 | TPTP20R | TPTP20R | TP20R | TP14 | Test pad |  |  |  |  |  |  |  |  |  |  |  |  |  |  |  |  |  |  |  |  |  |  |  | 2 |  |  |  |  |  |  |  |  |  |  | EPD_RST
1 | TPTP20R | TPTP20R | TP20R | TP4 | Test pad |  |  |  |  |  |  |  |  |  |  |  |  |  |  |  |  |  |  |  |  |  |  |  | 2 |  |  |  |  |  |  |  |  |  |  | GND
1 | TPTP20R | TPTP20R | TP20R | TP17 | Test pad |  |  |  |  |  |  |  |  |  |  |  |  |  |  |  |  |  |  |  |  |  |  |  | 2 |  |  |  |  |  |  |  |  |  |  | INT_RTC
1 | TPTP20R | TPTP20R | TP20R | TP8 | Test pad |  |  |  |  |  |  |  |  |  |  |  |  |  |  |  |  |  |  |  |  |  |  |  | 2 |  |  |  |  |  |  |  |  |  |  | MISO
1 | TPTP20R | TPTP20R | TP20R | TP9 | Test pad |  |  |  |  |  |  |  |  |  |  |  |  |  |  |  |  |  |  |  |  |  |  |  | 2 |  |  |  |  |  |  |  |  |  |  | MOSI
1 | TPTP20R | TPTP20R | TP20R | TP2 | Test pad |  |  |  |  |  |  |  |  |  |  |  |  |  |  |  |  |  |  |  |  |  |  |  | 2 |  |  |  |  |  |  |  |  |  |  | RX
1 | TPTP20R | TPTP20R | TP20R | TP10 | Test pad |  |  |  |  |  |  |  |  |  |  |  |  |  |  |  |  |  |  |  |  |  |  |  | 2 |  |  |  |  |  |  |  |  |  |  | SCK
1 | TPTP20R | TPTP20R | TP20R | TP1 | Test pad |  |  |  |  |  |  |  |  |  |  |  |  |  |  |  |  |  |  |  |  |  |  |  | 2 |  |  |  |  |  |  |  |  |  |  | TX
1 | TPTP20R | TPTP20R | TP20R | TP3 | Test pad |  |  |  |  |  |  |  |  |  |  |  |  |  |  |  |  |  |  |  |  |  |  |  | 2 |  |  |  |  |  |  |  |  |  |  | VBAT
1 | TPTP20R | TPTP20R | TP20R | TP16 | Test pad |  |  |  |  |  |  |  |  |  |  |  |  |  |  |  |  |  |  |  |  |  |  |  | 2 |  |  |  |  |  |  |  |  |  |  | VBUS
1 | USBLC6-2SC6Y | USBLC6-2SC6Y | SOT95P280X145-6N | D9 | Low Cap. ESD Protection Auto SOT-23-6 STMicroelectronics USBLC6-2SC6Y, Dual Uni-Directional TVS Diode Array, 6-Pin SOT-23 |  |  | In Stock |  | https://www.snapeda.com/parts/USBLC6-2SC6Y/STMicroelectronics/view-part/?ref=eda |  | https://ro.mouser.com/datasheet/2/389/usblc6_2sc6y-1852505.pdf | 17V Clamp 5A (8/20µs) Ipp Tvs Diode Surface Mount SOT-23-6 |  |  |  |  |  |  | STMicroelectronics |  |  | https://ro.mouser.com/ProductDetail/STMicroelectronics/USBLC6-2SC6Y?qs=gNDSiZmRJS%2FOgDexvXkdow== |  |  | USBLC6-2SC6Y |  | SOT-23-6 STMicroelectronics |  |  | None |  |  |  | https://www.snapeda.com/parts/USBLC6-2SC6Y/STMicroelectronics/view-part/?ref=snap
1 | W25Q512JVEIQ | W25Q512JVEIQ | SON127P600X800X80-9N | U3 | Check availability |  |  | In Stock |  | https://www.snapeda.com/parts/W25Q512JVEIQ/Winbond+Electronics/view-part/?ref=eda |  | https://www.winbond.com/resource-files/W25Q512JV%20SPI%20RevB%2006252019%20KMS.pdf | FLASH - NOR Memory IC 512Mb (64M x 8) SPI - Quad I/O 133 MHz 8-WSON (8x6) |  |  |  |  |  |  | Winbond Electronics |  |  |  |  |  | W25Q512JVEIQ |  | Package |  |  | None |  |  |  | https://www.snapeda.com/parts/W25Q512JVEIQ/Winbond+Electronics/view-part/?ref=snap
1 | XC6220A331MR-G | XC6220A331MR-G | SOT95P280X120-5N | IC2 | LDO Voltage Regulators |  |  |  |  |  |  | https://ro.mouser.com/datasheet/2/760/xc6220-3371556.pdf | LDO Voltage Regulators |  |  | 1.2mm |  | Torex | XC6220A331MR-G |  |  | 865-XC6220A331MR-G | https://www.mouser.co.uk/ProductDetail/Torex-Semiconductor/XC6220A331MR-G?qs=AsjdqWjXhJ8ZSWznL1J0gg%3D%3D

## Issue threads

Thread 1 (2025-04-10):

Capacitor has wrong value

raul-bosoanca, 2025-04-10:
The following capacitor has wrong value (100nF instead of 4.7uF) :

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

andreistan26, 2025-04-14:
Solved

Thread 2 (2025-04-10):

Schematic hard to read

raul-bosoanca, 2025-04-10:
Schematic has overlapping text that becomes hard to read (components names and types, values) :
For example :

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

andreistan26, 2025-04-14:
Solved

Closed 2025-04-14.

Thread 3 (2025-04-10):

Diode 3D model to small to fit PCB

raul-bosoanca, 2025-04-10:
The 3D model of the diode doesn't align with the pins of the PCB

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

The 3D model of the diode should be bigger, so the pins align

andreistan26, 2025-04-14:
The model matches the component, pads are touched.

Closed 2025-04-14.

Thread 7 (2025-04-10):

90 degrees angles on boot button routes

raul-bosoanca, 2025-04-10:
There are routes with straight angles on the button button

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

andreistan26, 2025-04-14:
Solved

Closed 2025-04-14.

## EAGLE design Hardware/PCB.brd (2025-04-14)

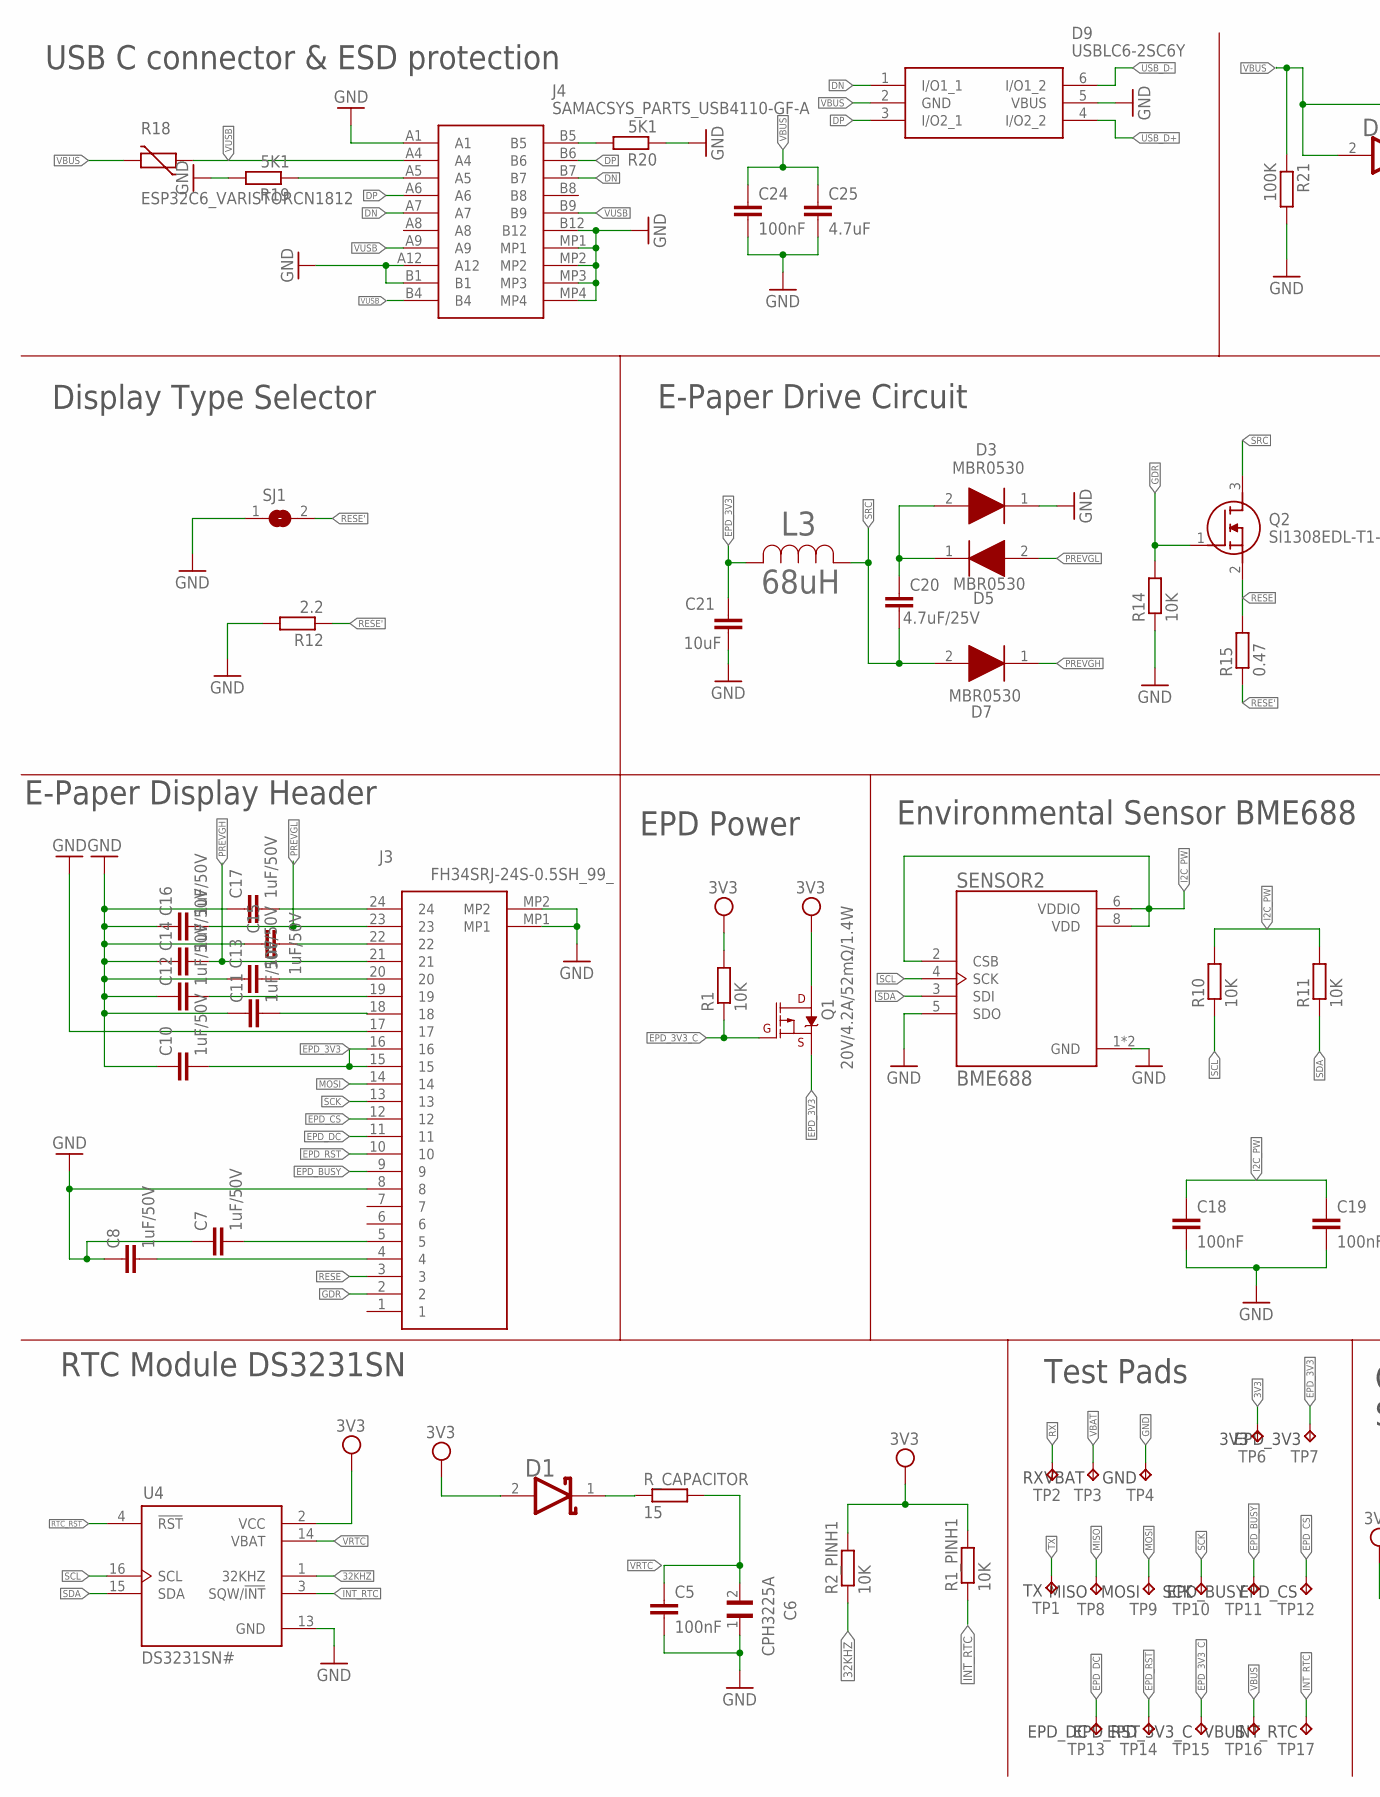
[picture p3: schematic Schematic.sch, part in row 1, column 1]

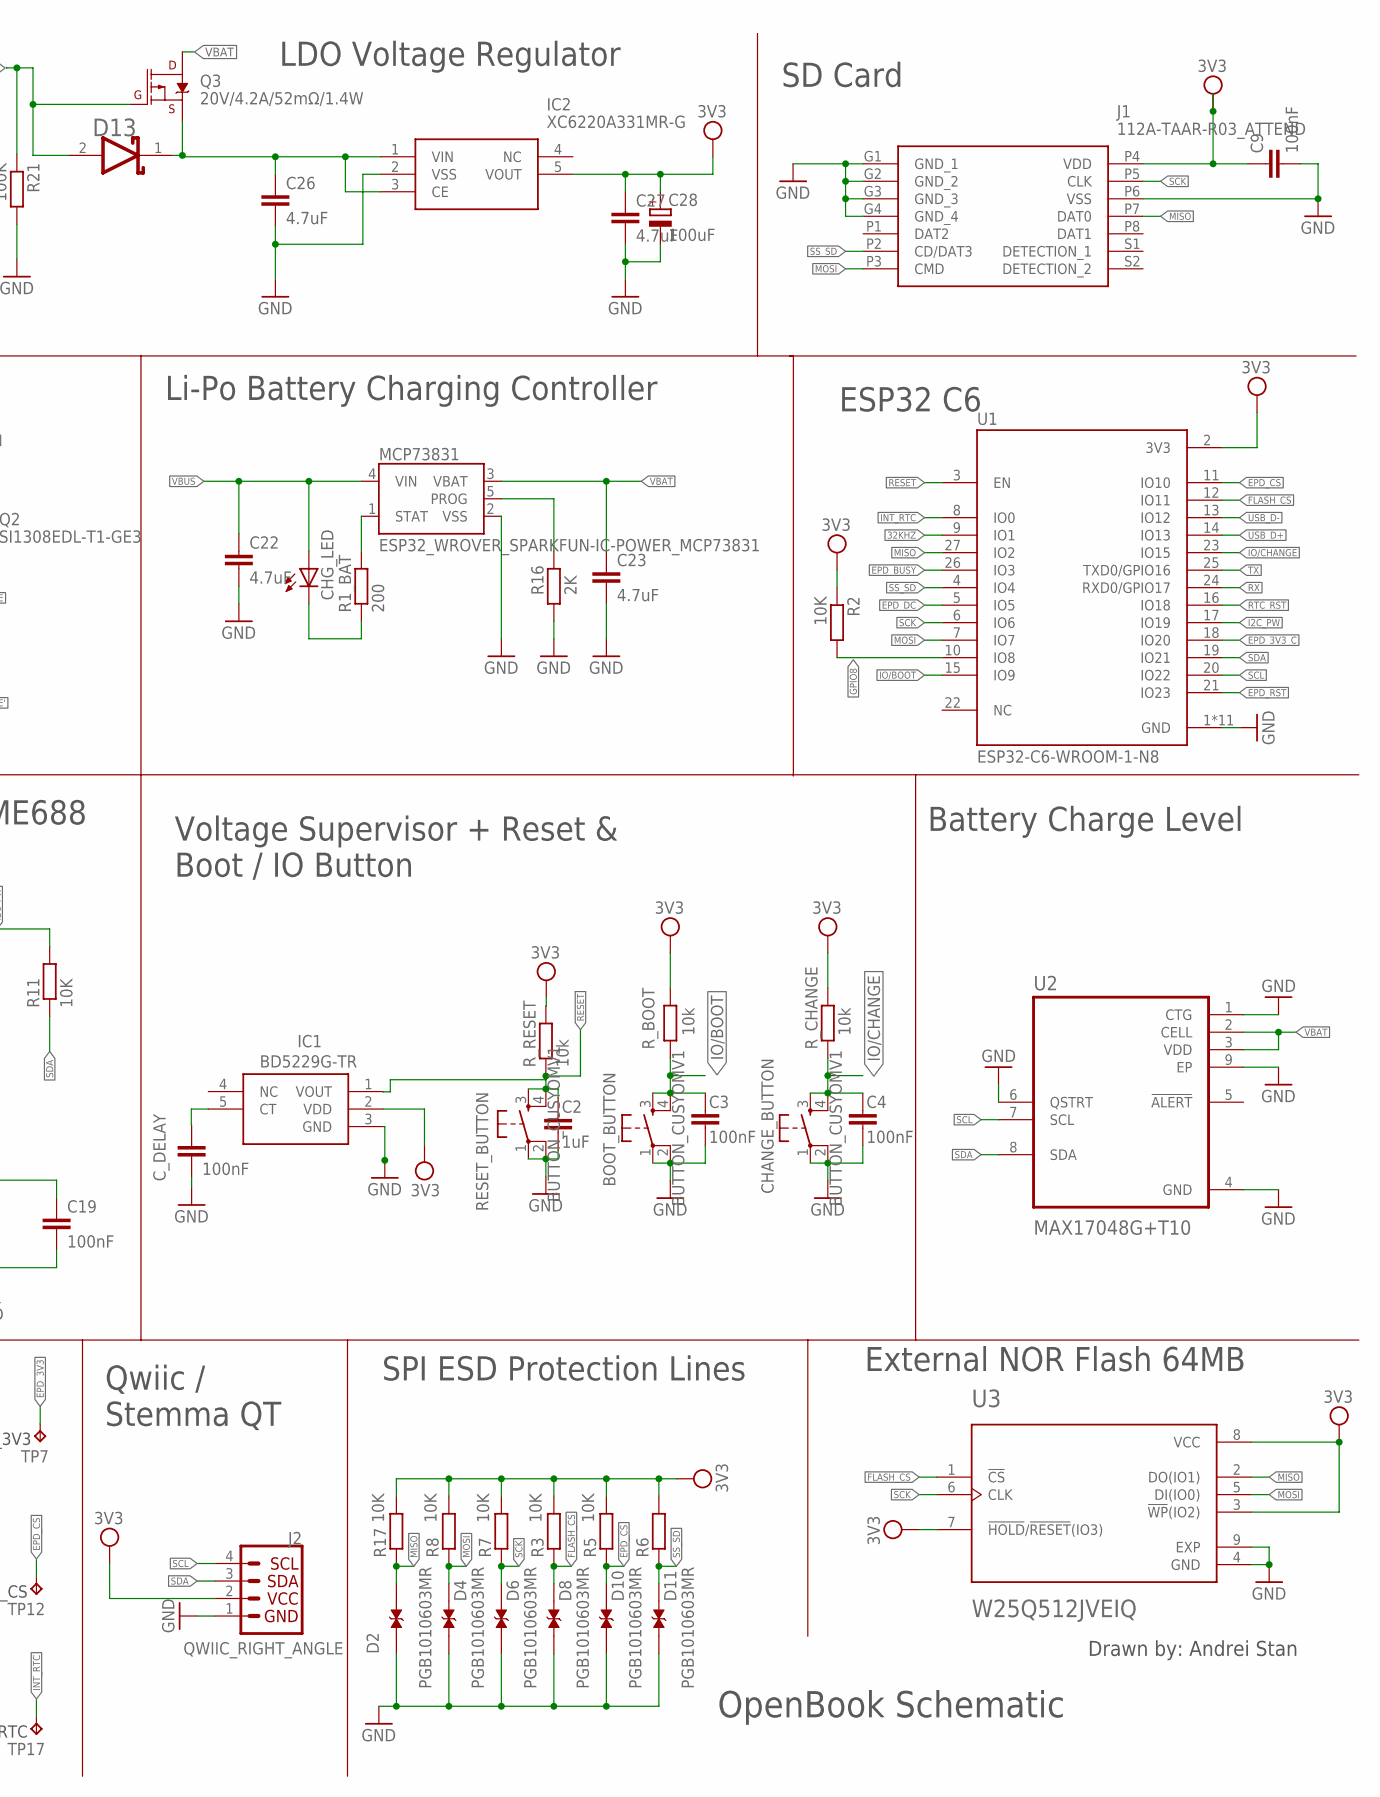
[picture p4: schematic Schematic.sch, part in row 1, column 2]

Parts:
BOOT_BUTTON: BUTTON_CUSYOMV1; MYBUTTON
C2: 1uF; EAGLE-LTSPICE_C0402
C3, C4, C5, C9, C18, C19: 100nF; EAGLE-LTSPICE_C0402
C6: CPH3225A; CAPCP3225X100N
C7, C8, C10, C11, C12, C13, C14, C15, C16, C17: 1uF/50V; EAGLE-LTSPICE_C0402
C20: 4.7uF/25V; ESP32_WROVER_EAGLE-LTSPICE_C0402
C21: 10uF; ESP32_WROVER_EAGLE-LTSPICE_C0402
C22, C23: 4.7uF; EAGLE-LTSPICE_C0402
C24: 100nF; ESP32_WROVER_EAGLE-LTSPICE_C0402
C25, C26, C27: 4.7uF; ESP32_WROVER_EAGLE-LTSPICE_C0402
C28: 100uF; RCL_CT3528
CHANGE_BUTTON: BUTTON_CUSYOMV1; MYBUTTON
CHG_LED: ADAFRUIT_LEDCHIP-LED0603; ADAFRUIT_CHIP-LED0603
C_DELAY: 100nF; EAGLE-LTSPICE_C0402
D1, D13: ESP32_WROVER_AVX---SD0805S020S1R0_AVX_SD0805S020S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; ESP32_WROVER_AVX---SD0805S020S1R0_AVX_SD0805S020S1R0_0
D2, D4, D6, D8, D10, D11: PGB1010603MR; DIOC1608X36N
D3, D5, D7: MBR0530; SOD3716X135N
D9: USBLC6-2SC6Y; SOT95P280X145-6N
IC1: BD5229G-TR; SOT95P280X125-5N
IC2: XC6220A331MR-G; SOT95P280X120-5N
J1: 112A-TAAR-R03_ATTEND; 112ATAARR03ATTEND
J2: QWIIC_RIGHT_ANGLE; JST04_1MM_RA
J3: FH34SRJ-24S-0.5SH_99_; FH34SRJ24S05SH99
J4: SAMACSYS_PARTS_USB4110-GF-A; SAMACSYS_PARTS_USB4110GFA
L3: 68uH; IND_4828-WE-TPC_WRE
MCP73831: ESP32_WROVER_SPARKFUN-IC-POWER_MCP73831; ESP32_WROVER_SPARKFUN-IC-POWER_SOT23-5
Q1, Q3: 20V/4.2A/52mΩ/1.4W; ESP32_WROVER_SPARKFUN-DISCRETESEMI_SOT23-3
Q2: SI1308EDL-T1-GE3; SOT65P210X110-3N
R1, R1_PINH1, R2, R2_PINH1, R3, R5, R6, R7, R8, R10, R11, R14, R17: 10K; ESP32_WROVER_EAGLE-LTSPICE_R0402
R1_BAT: 200; ESP32_WROVER_EAGLE-LTSPICE_R0402
R12: 2.2; ESP32_WROVER_EAGLE-LTSPICE_R0402
R15: 0.47; ESP32_WROVER_EAGLE-LTSPICE_R0402
R16: 2K; ESP32_WROVER_EAGLE-LTSPICE_R0402
R18: ESP32C6_VARISTORCN1812; ESP32C6_VARISTOR_CT/CN1812
R19, R20: 5K1; ESP32_WROVER_EAGLE-LTSPICE_R0402
R21: 100K; ESP32_WROVER_EAGLE-LTSPICE_R0402
RESET_BUTTON: BUTTON_CUSYOMV1; MYBUTTON
R_BOOT: 10k; ESP32_WROVER_EAGLE-LTSPICE_R0402
R_CAPACITOR: 15; ESP32_WROVER_EAGLE-LTSPICE_R0402
R_CHANGE: 10k; ESP32_WROVER_EAGLE-LTSPICE_R0402
R_RESET: 10k; ESP32_WROVER_EAGLE-LTSPICE_R0402
SENSOR2: BME688; ESP32_WROVER_BME680_PSON80P300X300X100-8N
SJ1: SJ
TP1, TP2, TP3, TP4, TP6, TP7, TP8, TP9, TP10, TP11, TP12, TP13, TP14, TP15, TP16, TP17: TPTP20R; TP20R
U1: ESP32-C6-WROOM-1-N8; XCVR_ESP32-C6-WROOM-1-N8
U2: MAX17048G+T10; SON50P200X200X80-9N
U3: W25Q512JVEIQ; SON127P600X800X80-9N
U4: DS3231SN#; SOIC127P1032X265-16N

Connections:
3V3: C9.1, C27.1, C28.+, D1.2 (ANODE), IC1.2 (VDD), IC2.5 (VOUT), J1.P4 (VDD), J2.2, Q1.3 (D), R1.2, R1_PINH1.2, R2.1, R2_PINH1.2, R3.2, R5.2, R6.2, R7.2, R8.2, R17.2, R_BOOT.2, R_CHANGE.2, R_RESET.2, TP6.TP, U1.2 (3V3), U3.3 (!WP!(IO2)), U3.7 (!HOLD!/!RESET!(IO3)), U3.8 (VCC), U4.2 (VCC)
32KHZ: R2_PINH1.1, U1.9 (IO1), U4.1 (32KHZ)
DN: D9.1 (I/O1_1), J4.A7, J4.B7
DP: D9.3 (I/O2_1), J4.A6, J4.B6
EPD_3V3: C10.2, C21.1, J3.15, J3.16, L3.2, Q1.2 (S), TP7.TP
EPD_3V3_C: Q1.1 (G), R1.1, TP15.TP, U1.18 (IO20)
EPD_BUSY: J3.9, TP11.TP, U1.26 (IO3)
EPD_CS: D10.2, J3.12, R5.1, TP12.TP, U1.11 (IO10)
EPD_DC: J3.11, TP13.TP, U1.5 (IO5)
EPD_RST: J3.10, TP14.TP, U1.21 (IO23)
FLASH_CS: D8.2, R3.1, U1.12 (IO11), U3.1 (!CS)
GDR: J3.2, Q2.1 (G), R14.2
GND: BOOT_BUTTON.1, BOOT_BUTTON.2, C2.2, C3.2, C4.2, C5.2, C6.1, C7.1, C8.1, C9.2, C10.1, C11.1, C12.1, C13.1, C14.1, C15.1, C16.1, C17.1, C18.2, C19.2, C21.2, C22.2, C23.2, C24.2, C25.2, C26.2, C27.2, C28.-, CHANGE_BUTTON.1, CHANGE_BUTTON.2, C_DELAY.2, D2.1, D3.1 (K), D4.1, D6.1, D8.1, D9.5 (VBUS), D10.1, D11.1, IC1.3 (GND), IC2.2 (VSS), J1.G1 (GND_1), J1.G2 (GND_2), J1.G3 (GND_3), J1.G4 (GND_4), J1.P6 (VSS), J2.1, J3.8, J3.17, J3.MP1, J3.MP2, J4.A1, J4.A12, J4.B1, J4.B12, J4.MP1, J4.MP2, J4.MP3, J4.MP4, MCP73831.2 (VSS), R12.2, R14.1, R16.1, R19.2, R20.1, R21.2, RESET_BUTTON.1, RESET_BUTTON.2, SENSOR2.1 (GND), SENSOR2.5 (SDO), SENSOR2.7 (GND), SJ1.1, TP4.TP, U1.1 (GND), U1.28 (GND), U1.29_1 (GND), U1.29_2 (GND), U1.29_3 (GND), U1.29_4 (GND), U1.29_5 (GND), U1.29_6 (GND), U1.29_7 (GND), U1.29_8 (GND), U1.29_9 (GND), U2.1 (CTG), U2.4 (GND), U2.6 (QSTRT), U2.9 (EP), U3.4 (GND), U3.9 (EXP), U4.13 (GND)
GPIO8: R2.2, U1.10 (IO8)
I2C_PW: C18.1, C19.1, R10.2, R11.2, SENSOR2.2 (CSB), SENSOR2.6 (VDDIO), SENSOR2.8 (VDD), U1.17 (IO19)
INT_RTC: R1_PINH1.1, TP17.TP, U1.8 (IO0), U4.3 (SQW/!INT)
IO/BOOT: BOOT_BUTTON.3, BOOT_BUTTON.4, C3.1, R_BOOT.1, U1.15 (IO9)
IO/CHANGE: C4.1, CHANGE_BUTTON.3, CHANGE_BUTTON.4, R_CHANGE.1, U1.23 (IO15)
MISO: D2.2, J1.P7 (DAT0), R17.1, TP8.TP, U1.27 (IO2), U3.2 (DO(IO1))
MOSI: D4.2, J1.P3 (CMD), J3.14, R8.1, TP9.TP, U1.7 (IO7), U3.5 (DI(IO0))
unnamed: C_DELAY.1, IC1.5 (CT)
unnamed: D1.1 (CATHODE), R_CAPACITOR.1
unnamed: C8.2, J3.4
unnamed: C7.2, J3.5
unnamed: C20.1, D3.2 (A), D5.1 (K)
unnamed: MCP73831.1 (STAT), R1_BAT.2
unnamed: J4.A5, R19.1
unnamed: CHG_LED.C, R1_BAT.1
unnamed: MCP73831.5 (PROG), R16.2
unnamed: J4.B5, R20.2
unnamed: C26.1, D13.1 (CATHODE), IC2.1 (VIN), IC2.3 (CE), Q3.2 (S)
unnamed: C11.2, J3.18
unnamed: C12.2, J3.19
unnamed: C13.2, J3.20
unnamed: C15.2, J3.22
unnamed: C17.2, J3.24
PREVGH: C14.2, D7.1 (K), J3.21
PREVGL: C16.2, D5.2 (A), J3.23
RESE: J3.3, Q2.2 (S), R15.2
RESE': R12.1, R15.1, SJ1.2
RESET: C2.1, IC1.1 (VOUT), RESET_BUTTON.3, RESET_BUTTON.4, R_RESET.1, U1.3 (EN)
RTC_RST: U1.16 (IO18), U4.4 (!RST)
RX: TP2.TP, U1.24 (RXD0/GPIO17)
SCK: D6.2, J1.P5 (CLK), J3.13, R7.1, TP10.TP, U1.6 (IO6), U3.6 (CLK)
SCL: J2.4, R10.1, SENSOR2.4 (SCK), U1.20 (IO22), U2.7 (SCL), U4.16 (SCL)
SDA: J2.3, R11.1, SENSOR2.3 (SDI), U1.19 (IO21), U2.8 (SDA), U4.15 (SDA)
SRC: C20.2, D7.2 (A), L3.1, Q2.3 (D)
SS_SD: D11.2, J1.P2 (CD/DAT3), R6.1, U1.4 (IO4)
TX: TP1.TP, U1.25 (TXD0/GPIO16)
USB_D+: D9.4 (I/O2_2), U1.14 (IO13)
USB_D-: D9.6 (I/O1_2), U1.13 (IO12)
VBAT: C23.1, MCP73831.3 (VBAT), Q3.3 (D), TP3.TP, U2.2 (CELL), U2.3 (VDD)
VBUS: C22.1, C24.1, C25.1, CHG_LED.A, D9.2 (GND), D13.2 (ANODE), MCP73831.4 (VIN), Q3.1 (G), R18.2, R21.1, TP16.TP
VRTC: C5.1, C6.2, R_CAPACITOR.2, U4.14 (VBAT)
VUSB: J4.A4, J4.A9, J4.B4, J4.B9, R18.1

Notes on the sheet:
OpenBook Schematic
Drawn by: Andrei Stan
External NOR Flash 64MB
Battery Charge Level
ESP32 C6
SD Card
Qwiic / Stemma QT
SPI ESD Protection Lines
Test Pads
RTC Module DS3231SN
E-Paper Display Header
EPD Power
Voltage Supervisor + Reset & Boot / IO Button
Environmental Sensor BME688
Li-Po Battery Charging Controller
E-Paper Drive Circuit
LDO Voltage Regulator
Display Type Selector
USB C connector & ESD protection

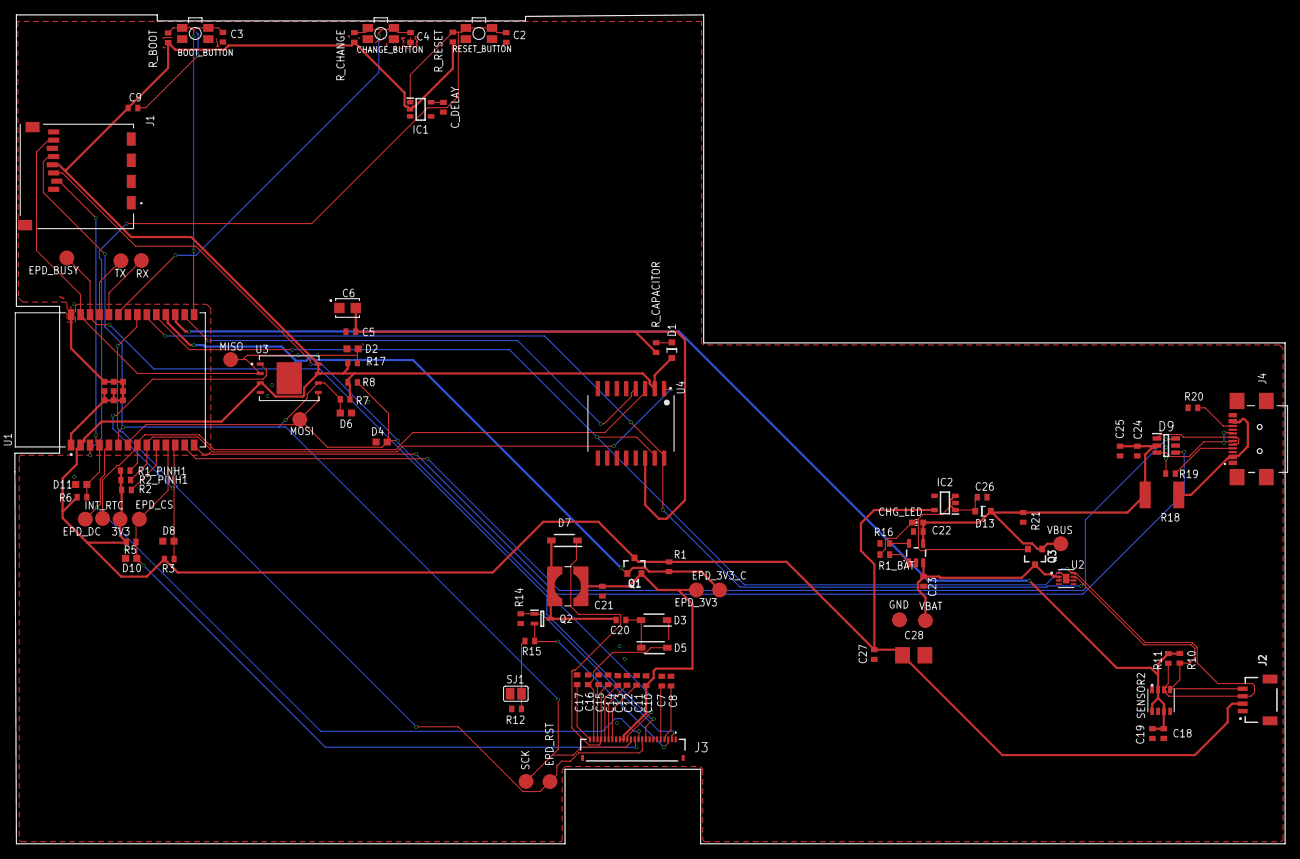
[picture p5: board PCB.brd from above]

Board: 2 copper layers, 170.4 x 111.2 mm, 102 parts (0 on the bottom side), 55 nets.

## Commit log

2025-04-05 Add gerber.zip
2025-04-14 fix issues
    [PCB.brd, Schematic.sch]

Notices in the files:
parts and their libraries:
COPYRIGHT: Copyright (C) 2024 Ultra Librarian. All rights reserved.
